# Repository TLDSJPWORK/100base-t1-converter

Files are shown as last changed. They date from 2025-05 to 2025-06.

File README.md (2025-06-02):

# 100base-t1-converter for Education
学習用 100Base-T1 MediaConnverter

### 特徴
- NXP社のTJA1101とCoreChips社のSR8201F（Realtek社 RTL8201F互換）を使用した 100Base-T1 <-> 100Base-TX のMediaConverterです。
- STM32F103C8T6を搭載したBlue Pill[参考URL](https://en.wikipedia.org/wiki/STM32)を使うことでPHYの設定をMDIOを用いて確認／実施することができ、PHY層の動きを学習することができます。
- オリジナルは Creative Commons Attribution-ShareAlike 4.0 International ライセンスで公開されている[100base-t1-converter](https://github.com/ehntoo/100base-t1-converter)です。作者はehntoo様です。
- 本プロダクトはベースプロダクトから、MDIOでPHYの設定を読み書きするプログラムを追加し、また、[LCSC](https://www.lcsc.com/)で部品を注文するための具体的な部品番号の追加および部品配置の変更と、基板を[JLCPCB](https://jlcpcb.com/)でより安く注文できるように最小ドリル径を変更したものとなります。
- 本プロダクトのライセンスは Creative Commons Attribution-ShareAlike 4.0 International を継承します。

### 基板
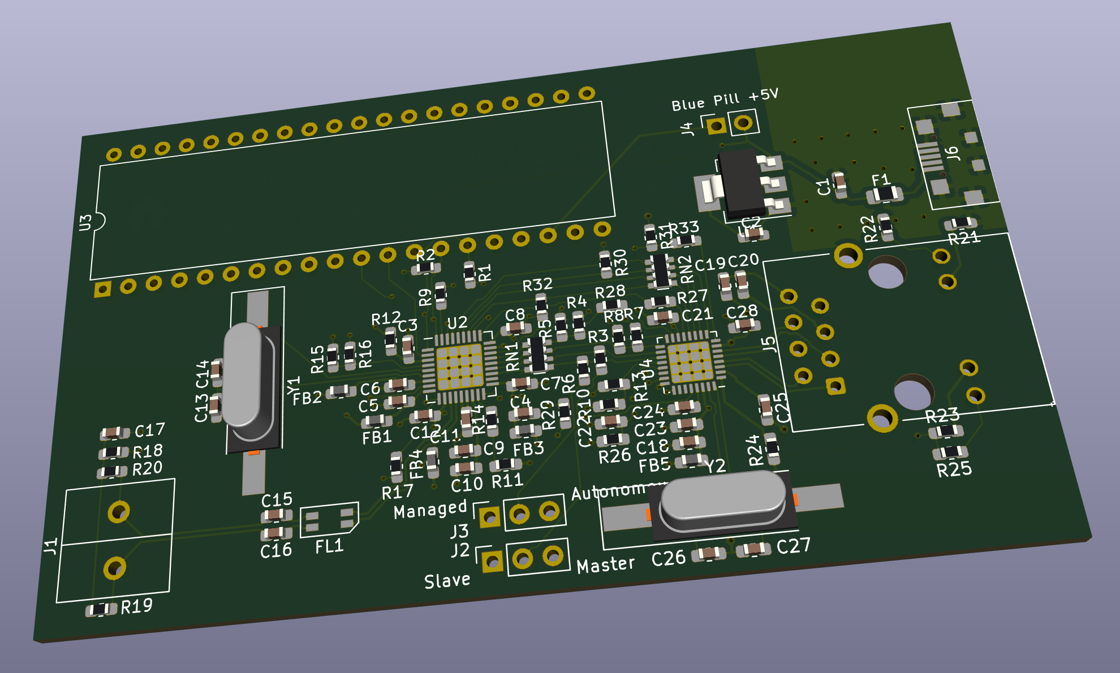
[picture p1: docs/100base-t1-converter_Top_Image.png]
TopImage

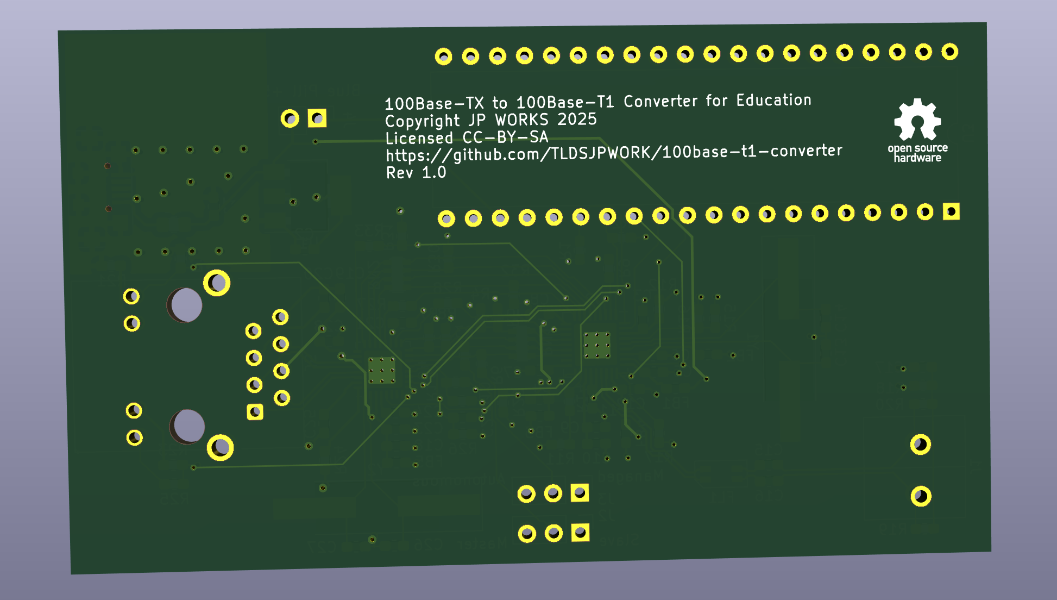
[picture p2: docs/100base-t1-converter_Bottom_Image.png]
BottomImage

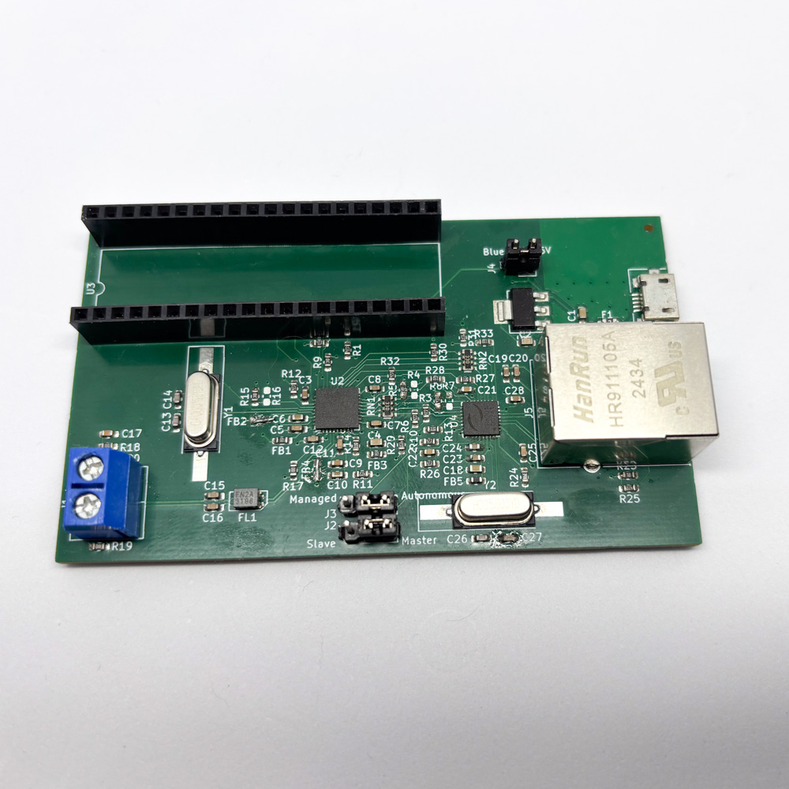
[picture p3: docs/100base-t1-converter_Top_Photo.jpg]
TopPhoto

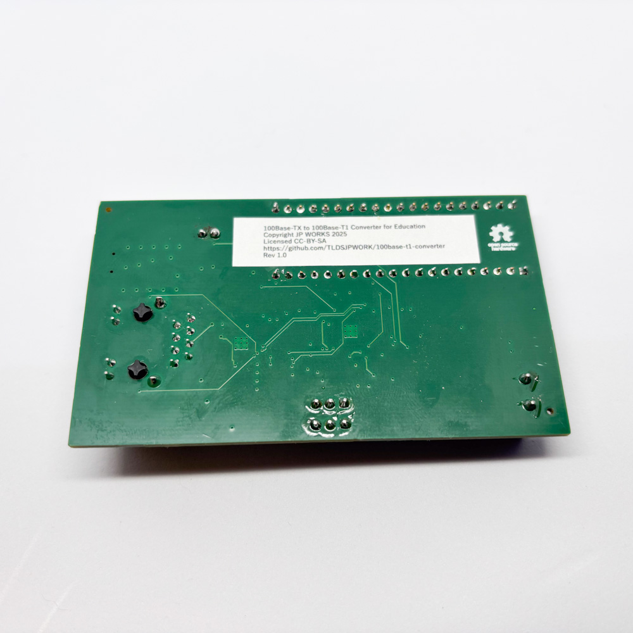
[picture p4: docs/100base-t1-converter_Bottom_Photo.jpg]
BottomPhoto

（※基盤イメージ／写真は参考であり、改良のため変更することがあります）

### 基板の設定
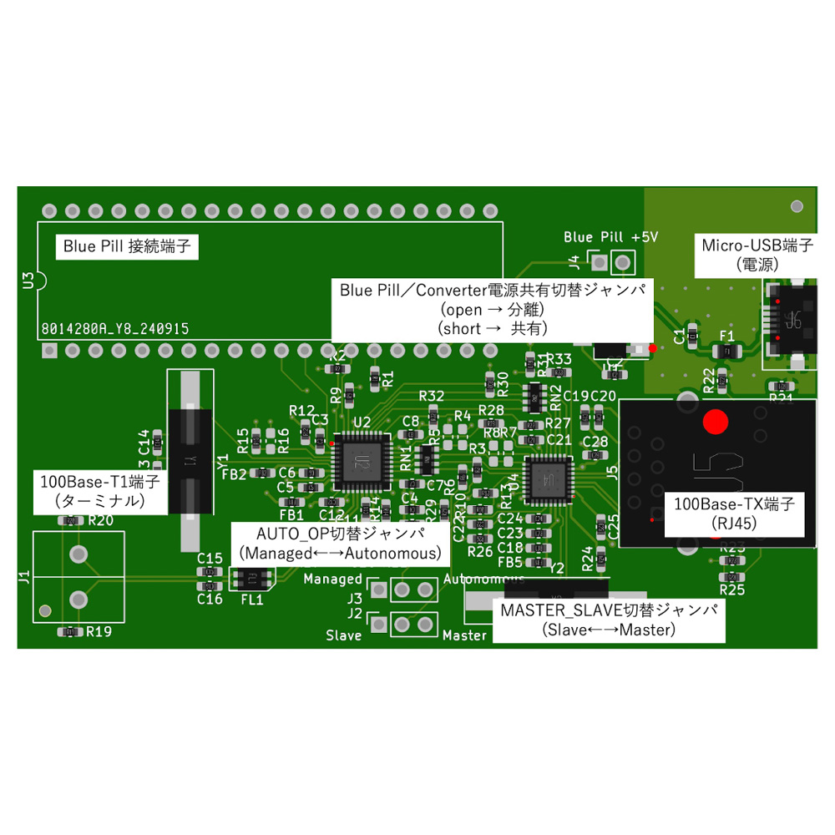
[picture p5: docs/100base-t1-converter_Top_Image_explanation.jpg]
TopImageExplanation


### 使用例
- メディアコンバータとして利用するだけならば、下記ジャンパの設定で、Blue Pillとそれに書き込むソフトウェアの対応は不要です。

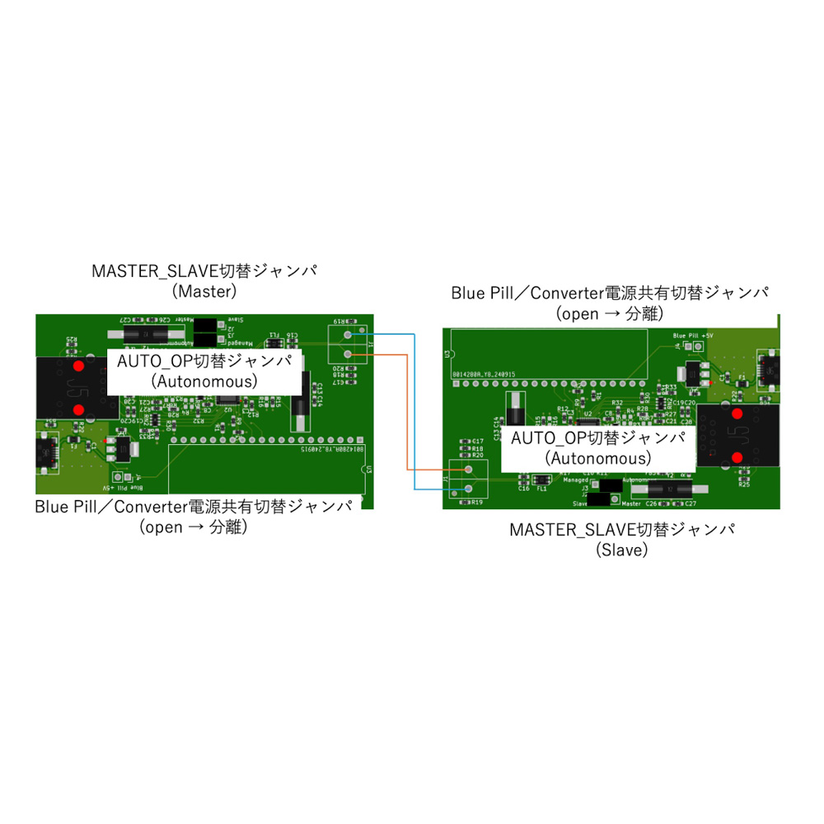
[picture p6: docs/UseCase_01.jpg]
UseCase_01


- Blue Pillにソフトウェアを書き込むことで、MDIOを通してPYHチップの動作確認、変更が可能です。

[レジスター読み書きソフト](/software/phyRegRead/)

- Blue PillをArduinoとして利用し、上記ソフトを書き込むことで、レジスターの読み書きができます。

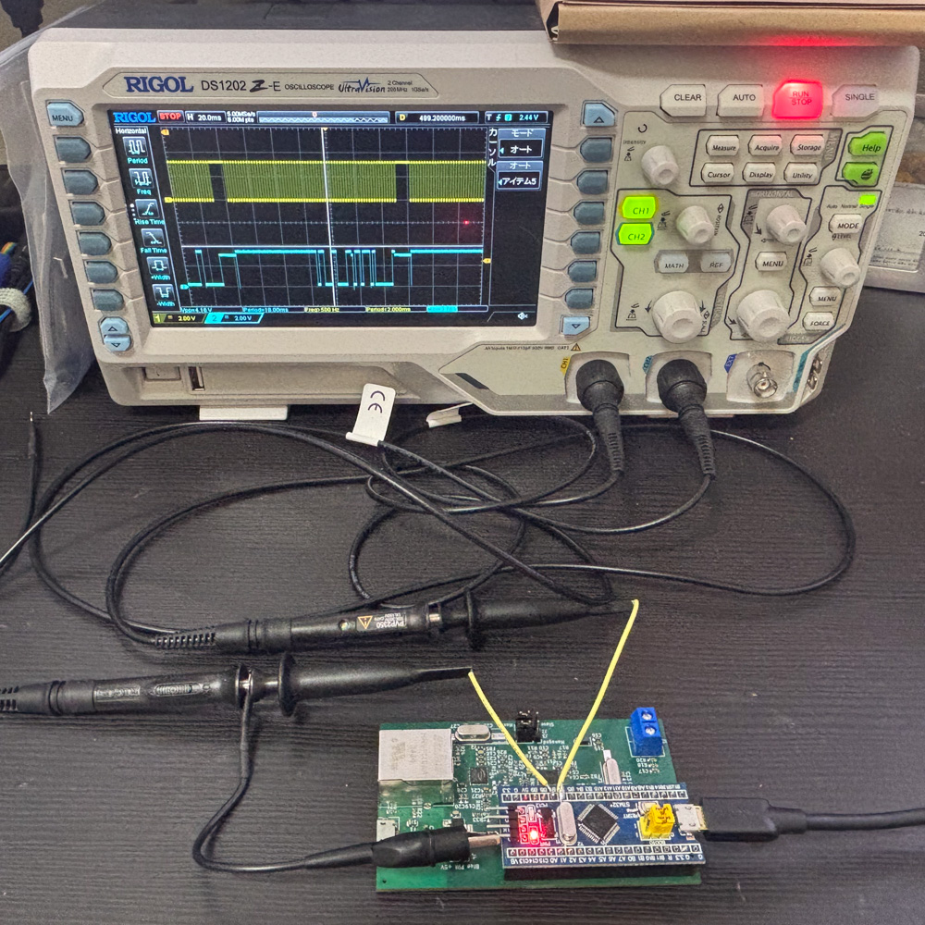
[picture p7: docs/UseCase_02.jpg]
UseCase_03

（ch1がPB7のMDC(Clock)、ch2がPB6のMDIO(Data)です）

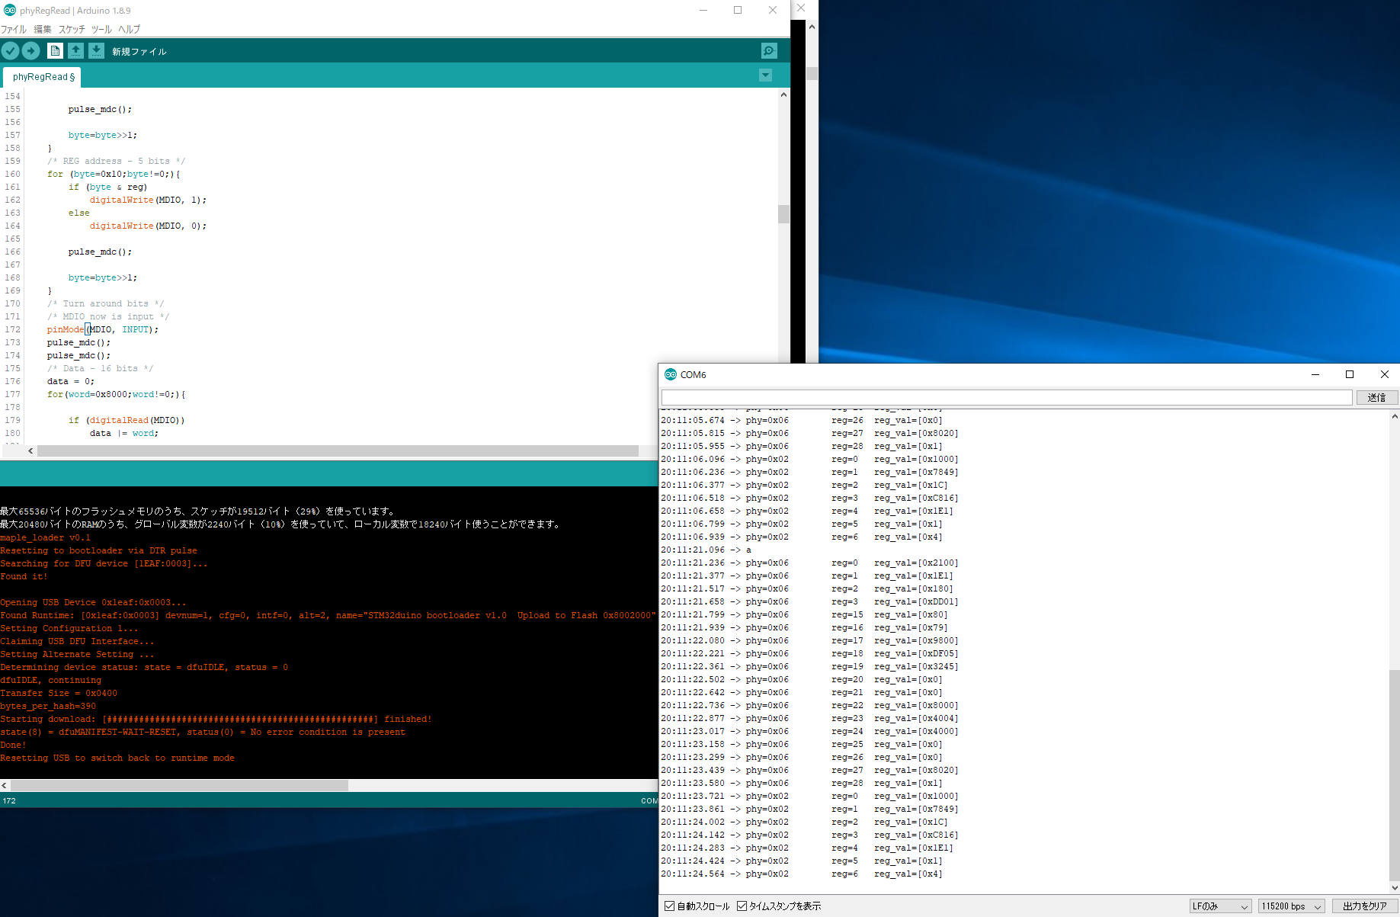
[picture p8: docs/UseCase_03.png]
UseCase_04


- PHYADDR：TJA1101=0x06, SR8201F=0x02
- シリアルコマンド：a 送信=全レジスタ読み出し, r (phyaddr) (register number) 送信=指定レジスタ読出, w (phyaddr) (register number) (レジスタ値) 送信=指定レジスタ書込

### 販売ページ

- スイッチサイエンス様

### 資料

- [サポートページ](https://github.com/TLDSJPWORK/100base-t1-converter)
- [回路図](docs/100base-t1-converter.pdf)
- [TJA1101データシート](https://www.nxp.com/docs/en/data-sheet/TJA1101B.pdf)
- [SR8201Fデータシート](https://www.lcsc.com/datasheet/lcsc_datasheet_2409272302_CoreChips-SR8201F_C378491.pdf) 
- [Blue Pill](https://en.wikipedia.org/wiki/STM32)
- [STM32F103 ボードを Arduino ライクに使う](https://ht-deko.com/arduino/stm32f103c8t6.html)
- [MDIOとは | Ethernet(イーサネット)技術コラム](https://www.e-nexty.com/static/articles/column_ethernet_mdio)

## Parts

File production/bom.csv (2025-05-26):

Designator | Footprint | Quantity | Value | LCSC Part #
C1, C18, C2, C4 | 603 | 4 | 10uF | C96446
C10, C6, C9 | 603 | 3 | 0.47uF | C1623
C11, C12, C15, C16, C19, C20, C21, C22, C23, C24, C25, C28, C3, C5, C7, C8 | 603 | 16 | 0.1uF | C14663
C13, C14, C26, C27 | 603 | 4 | 27pF | C1647
C17 | 603 | 1 | 4700pF | C53987
F1 | 805 | 1 | 500mA | C516070
FB1, FB3 | 603 | 2 | 120R | C22787
FB2, FB4 | 603 | 2 | 0
FB5 | 603 | 1 | BLM18PG181SN1D | C82850
FL1 | SOIC-4 | 1 | ACT1210L-201-2P-TL00 | C131444
J1 | SIP-2 | 1 | Conn_01x02
J2, J3 | PinSocket_1x03_P2.54mm_Vertical | 2 | Conn_01x03
J4 | PinSocket_1x02_P2.54mm_Vertical | 1 | Conn_01x02
J5 | RJ45_Hanrun_HR911105A | 1 | 8P8C_LED_Shielded | C12074
J6 | LCSC_C77238 | 1 | USB_B_Micro | C77238
R1, R10, R11, R12, R2, R22, R25, R26, R29, R3, R30, R31, R32, R6 | 603 | 14 | 4.7k | C23162
R13, R14, R27, R28, R33 | 603 | 5 | 33 | C23140
R15, R9 | 603 | 2 | 10k | C25804
R16, R4, R5, R7, R8 | 603 | 5 | DNP
R17, R18 | 603 | 2 | 100k | C25803
R19, R20 | 603 | 2 | 1.0k | C21190
R21, R23 | 603 | 2 | 510 | C23193
R24 | 603 | 1 | 2.49k 1% | C108190
RN1 | R_Array_Convex_Reversed_4x0603 | 1 | 33 | C25508
RN2 | R_Array_Convex_Reversed_4x0603 | 1 | 33R | C25508
U1 | SOT-223-3_TabPin2 | 1 | AP1117-33 | C115288
U2 | QFN-36-1EP_6x6mm_P0.5mm_EP4.1x4.1mm_ThermalVias | 1 | TJA1101 | C2671511
U3 | DIP-40_W15.24mm | 1 | blue_pill
U4 | QFN-32-1EP_5x5mm_P0.5mm_EP3.6x3.6mm_ThermalVias | 1 | SR8201F | C378491
Y1, Y2 | Crystal_SMD_HC49-SD_HandSoldering | 2 | TXC 9C25000026 | C2890202

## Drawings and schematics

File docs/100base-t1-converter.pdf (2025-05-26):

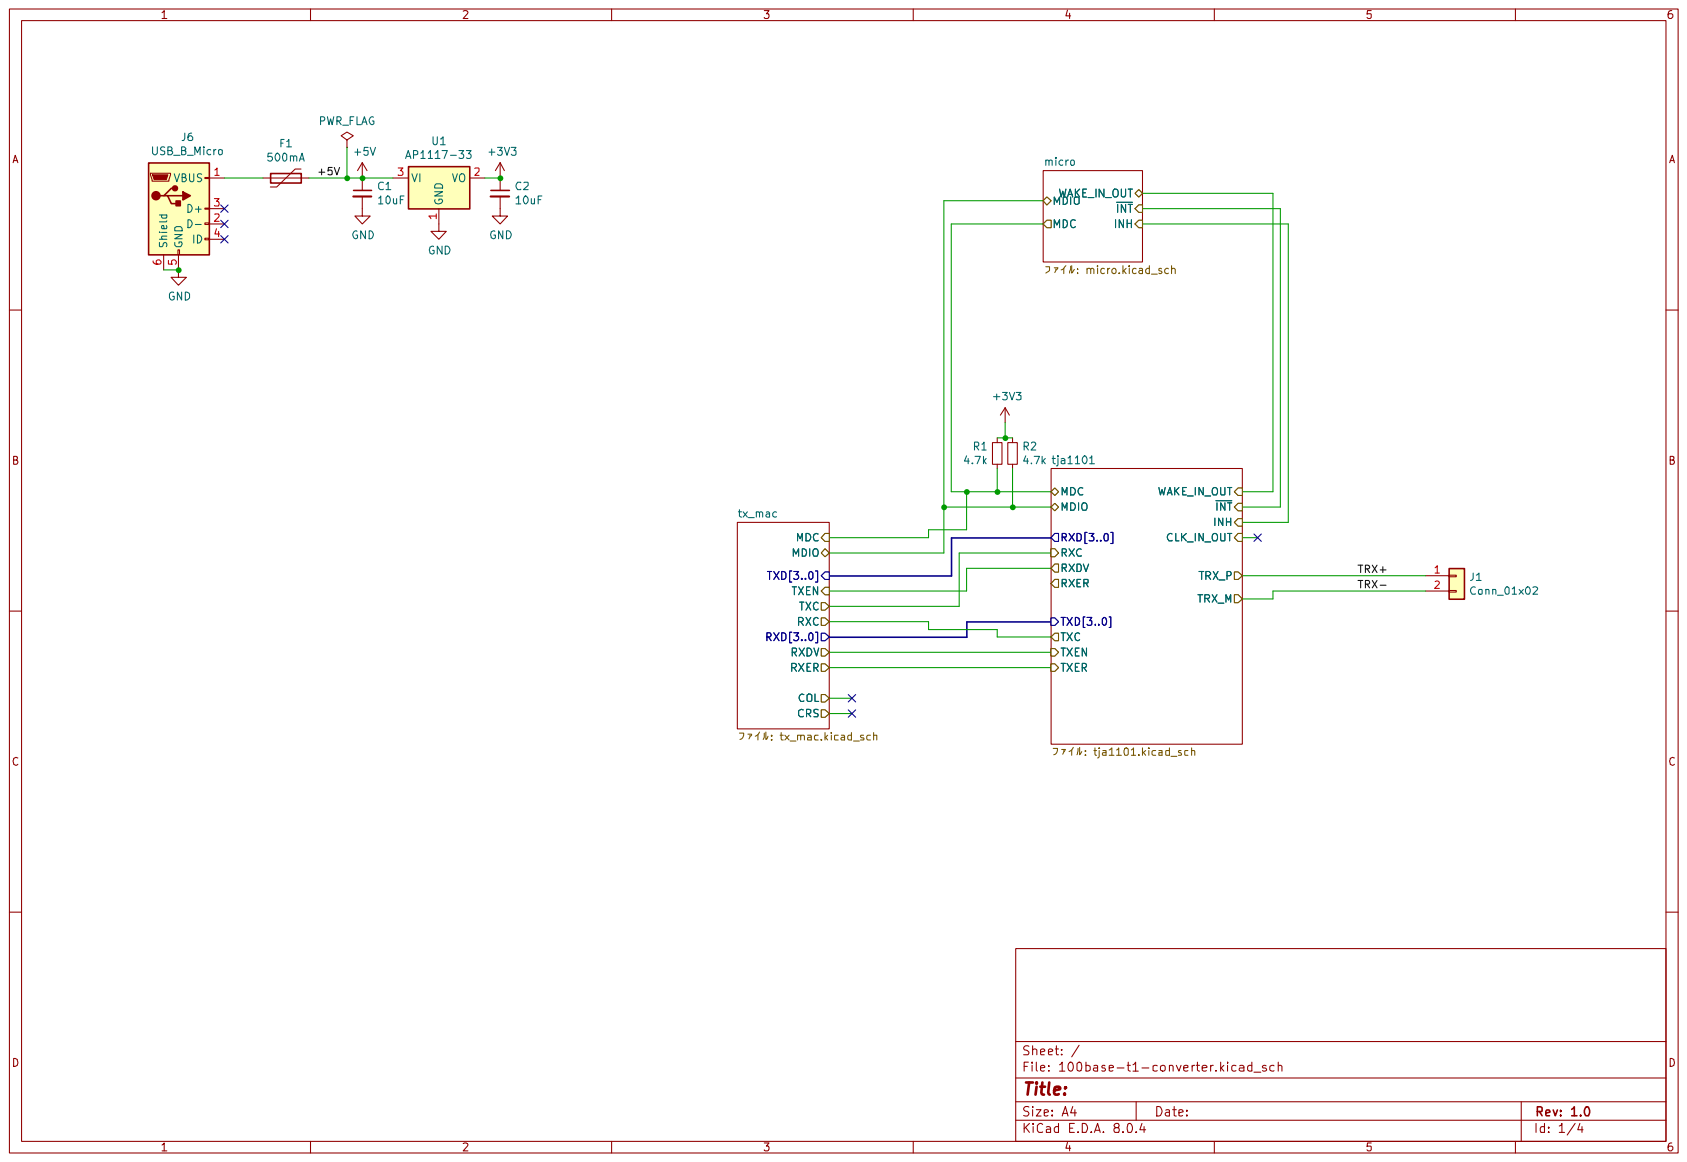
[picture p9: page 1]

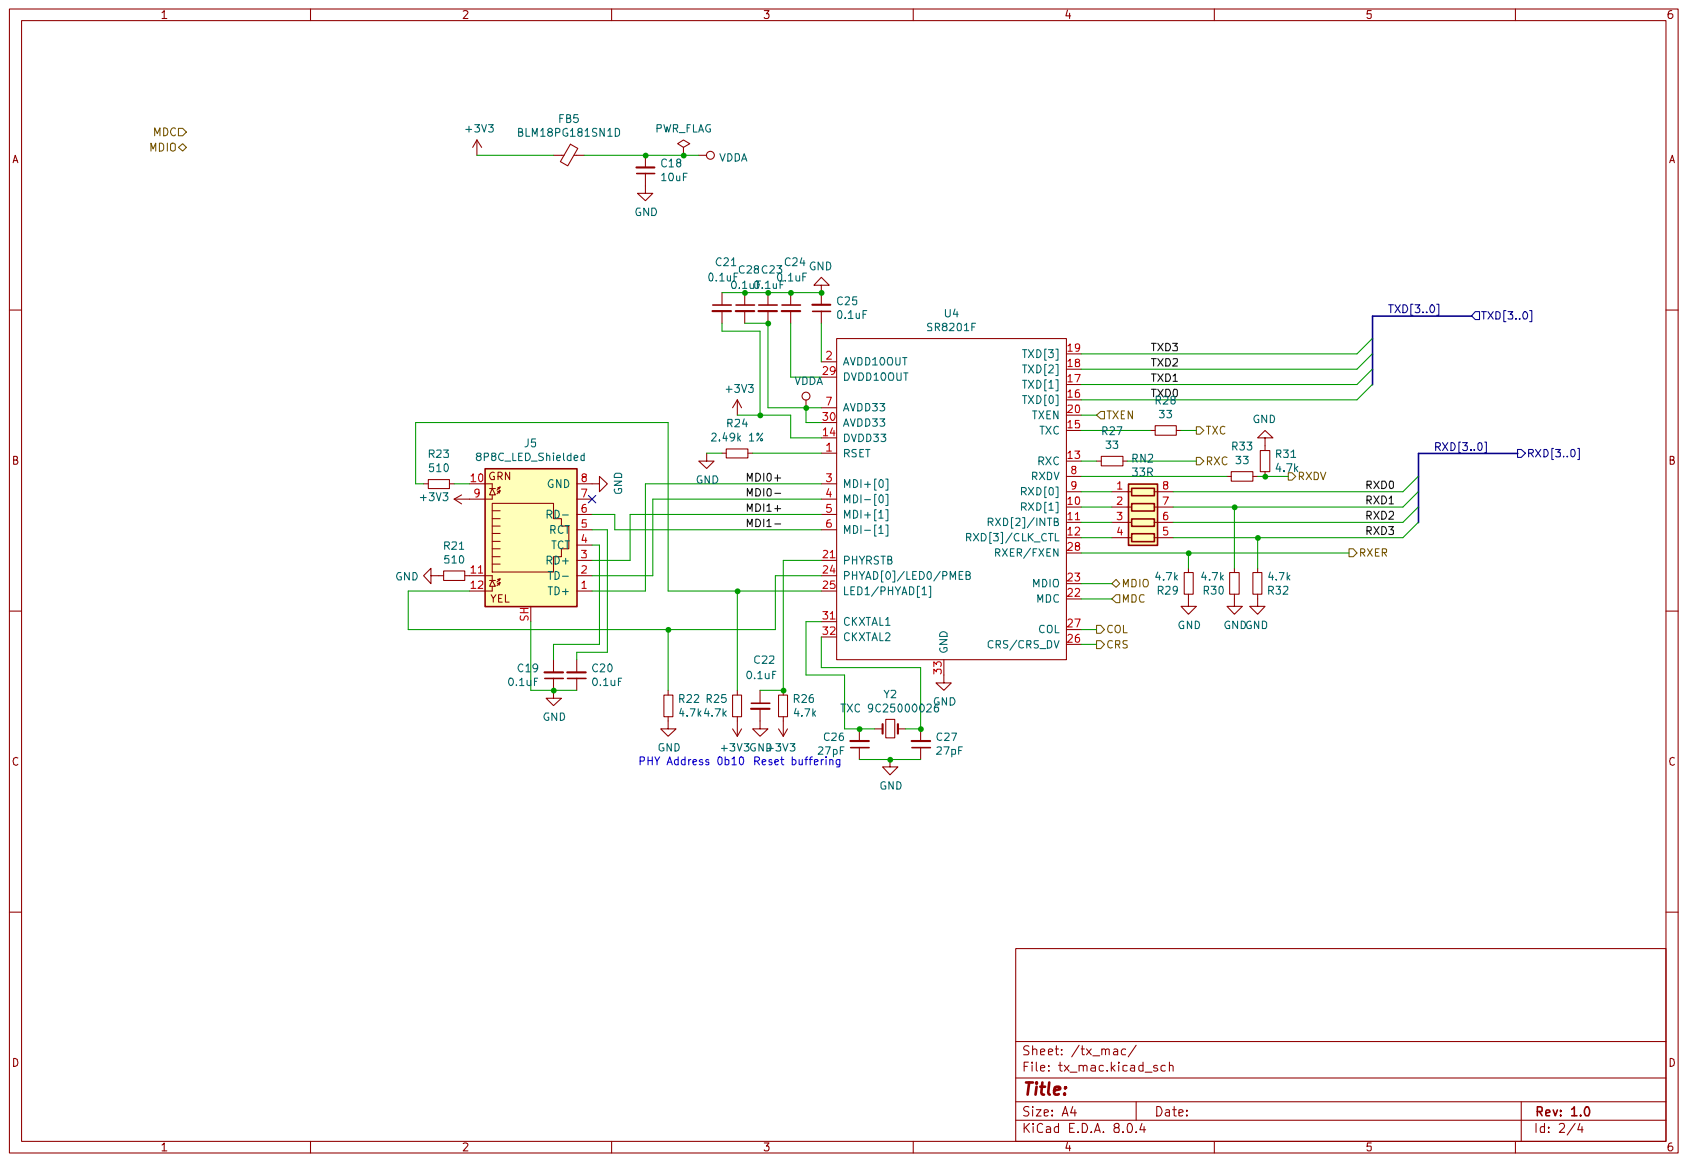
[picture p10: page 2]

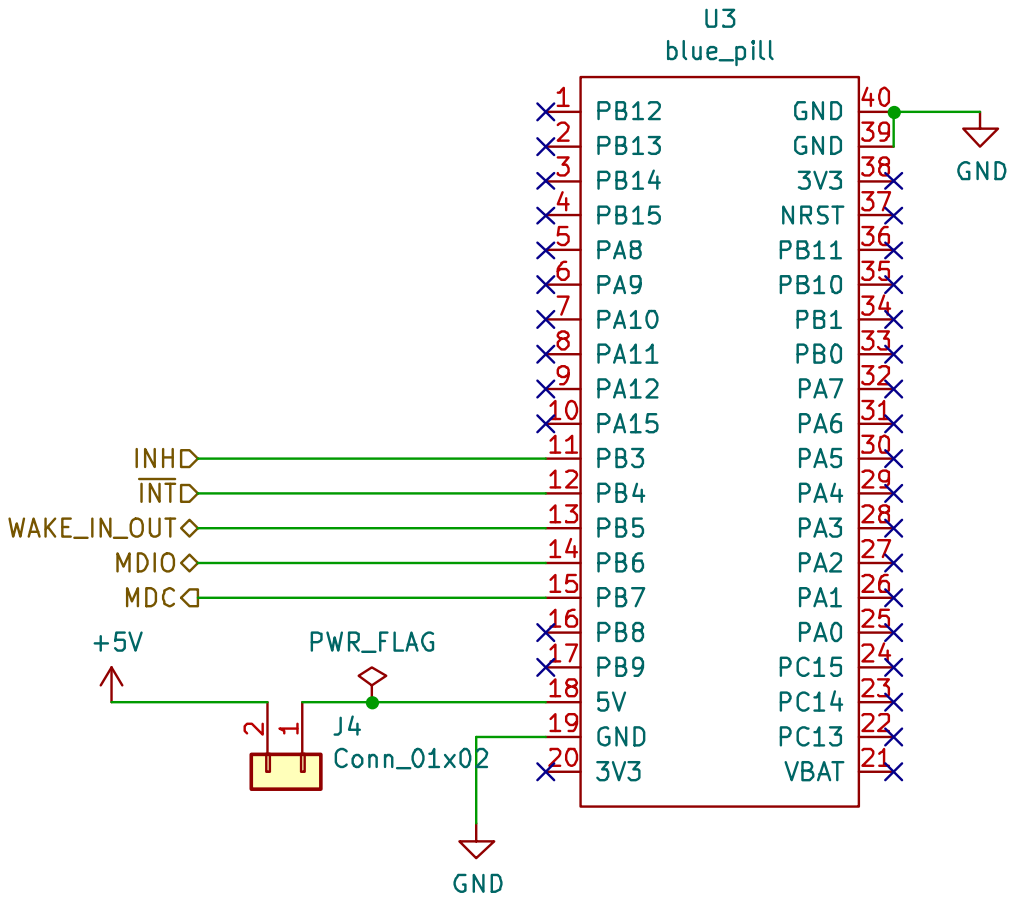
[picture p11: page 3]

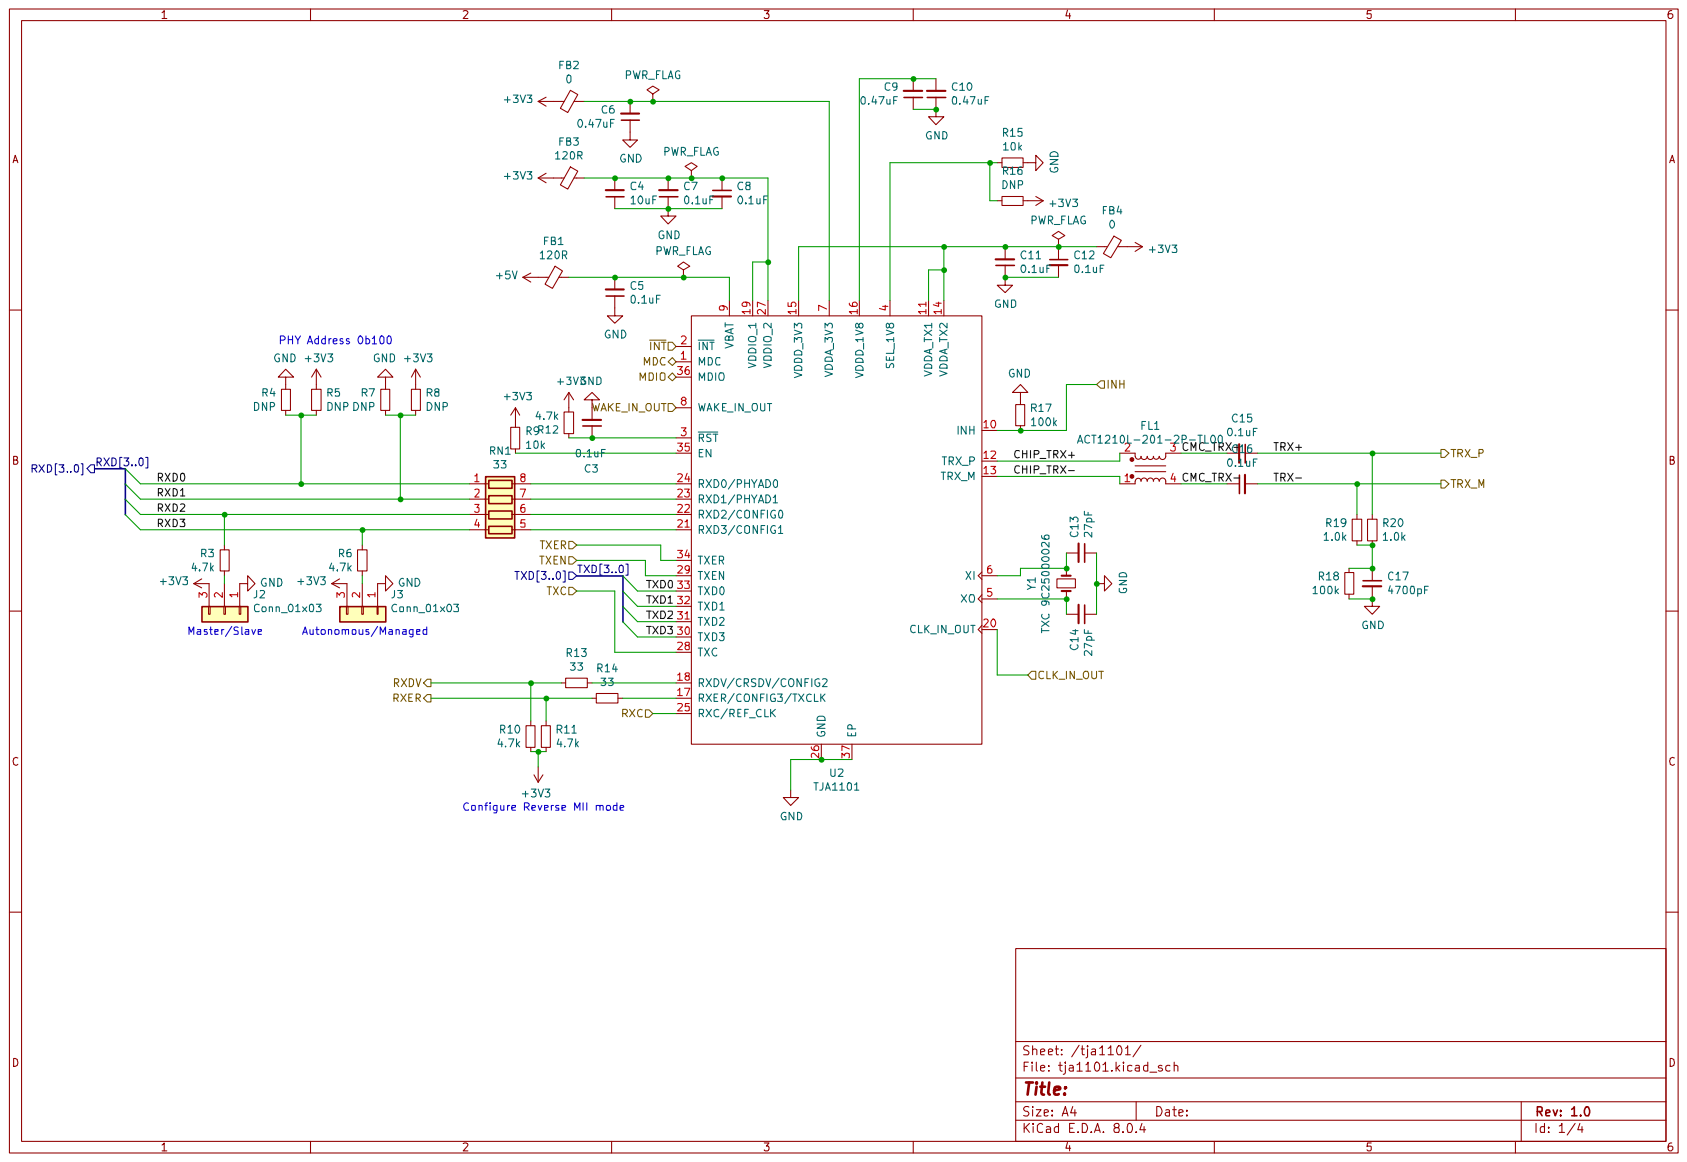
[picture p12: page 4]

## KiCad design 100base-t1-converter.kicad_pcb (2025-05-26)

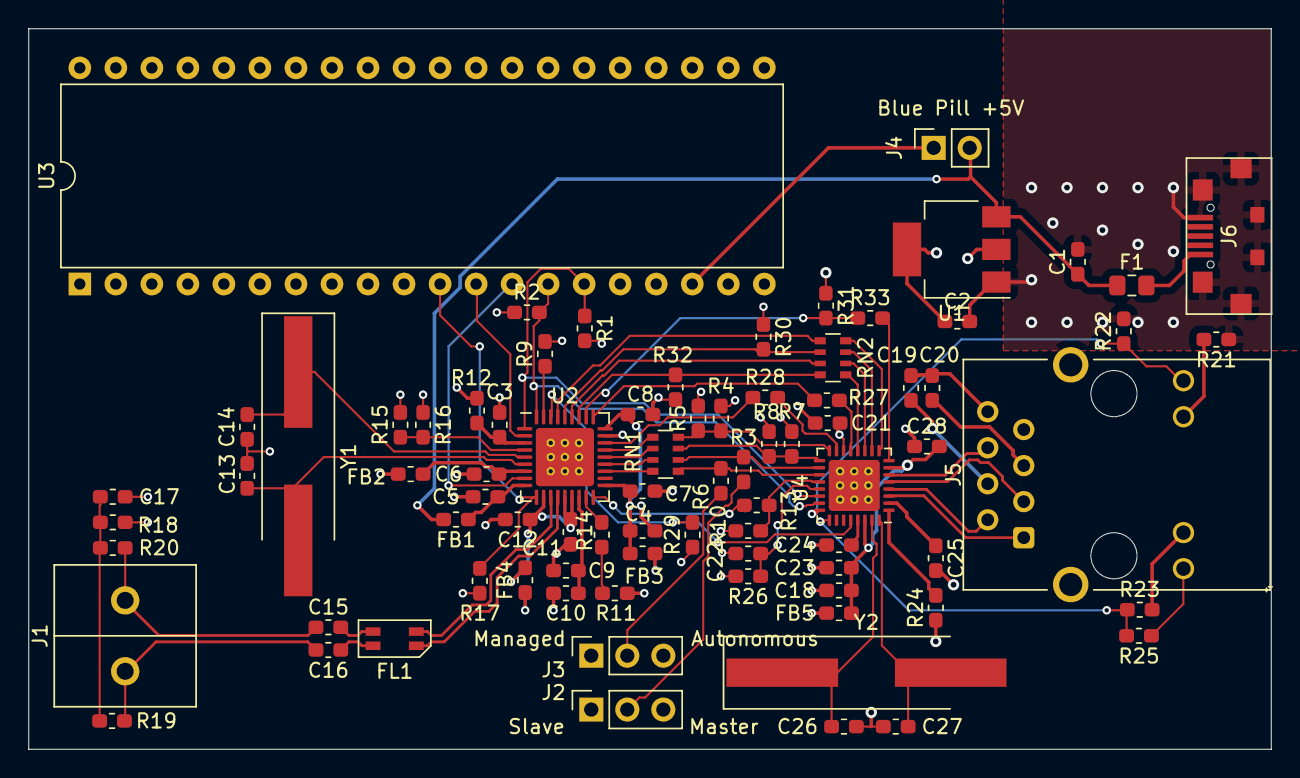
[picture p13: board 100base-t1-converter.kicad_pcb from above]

Board: 4 copper layers, 87.6 x 50.8 mm, 82 parts (0 on the bottom side), 50 nets.

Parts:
C1, C2, C4, C18: 10uF; C_0603_1608Metric_Pad1.05x0.95mm_HandSolder
C3, C5, C7, C8, C11, C12, C15, C16, C19, C20, C21, C22, C23, C24, C25, C28: 0.1uF; C_0603_1608Metric_Pad1.05x0.95mm_HandSolder
C6, C9, C10: 0.47uF; C_0603_1608Metric_Pad1.05x0.95mm_HandSolder
C13, C14, C26, C27: 27pF; C_0603_1608Metric_Pad1.05x0.95mm_HandSolder
C17: 4700pF; C_0603_1608Metric_Pad1.05x0.95mm_HandSolder
F1: 500mA; Fuse_0805_2012Metric_Pad1.15x1.40mm_HandSolder
FB1, FB3: 120R; L_0603_1608Metric_Pad1.05x0.95mm_HandSolder
FB2, FB4: 0; L_0603_1608Metric_Pad1.05x0.95mm_HandSolder
FB5: BLM18PG181SN1D; L_0603_1608Metric_Pad1.05x0.95mm_HandSolder
FL1: ACT1210L-201-2P-TL00; SOIC-4
J1: Conn_01x02; SIP-2
J2, J3: Conn_01x03; PinSocket_1x03_P2.54mm_Vertical
J4: Conn_01x02; PinSocket_1x02_P2.54mm_Vertical
J5: 8P8C_LED_Shielded; RJ45_Hanrun_HR911105A
J6: USB_B_Micro; LCSC_C77238
R1, R2, R3, R6, R10, R11, R12, R22, R25, R26, R29, R30, R31, R32: 4.7k; R_0603_1608Metric_Pad1.05x0.95mm_HandSolder
R4, R5, R7, R8, R16: DNP; R_0603_1608Metric_Pad1.05x0.95mm_HandSolder
R9, R15: 10k; R_0603_1608Metric_Pad1.05x0.95mm_HandSolder
R13, R14, R27, R28, R33: 33; R_0603_1608Metric_Pad1.05x0.95mm_HandSolder
R17, R18: 100k; R_0603_1608Metric_Pad1.05x0.95mm_HandSolder
R19, R20: 1.0k; R_0603_1608Metric_Pad1.05x0.95mm_HandSolder
R21, R23: 510; R_0603_1608Metric_Pad1.05x0.95mm_HandSolder
R24: 2.49k 1%; R_0603_1608Metric_Pad1.05x0.95mm_HandSolder
RN1: 33; R_Array_Convex_Reversed_4x0603
RN2: 33R; R_Array_Convex_Reversed_4x0603
U1: AP1117-33; SOT-223-3_TabPin2
U2: TJA1101; QFN-36-1EP_6x6mm_P0.5mm_EP4.1x4.1mm_ThermalVias
U3: blue_pill; DIP-40_W15.24mm
U4: SR8201F; QFN-32-1EP_5x5mm_P0.5mm_EP3.6x3.6mm_ThermalVias
Y1, Y2: TXC 9C25000026; Crystal_SMD_HC49-SD_HandSoldering

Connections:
+3V3: C2.1, C21.2, FB2.2, FB3.2, FB4.1, FB5.2, J2.3, J3.3, J5.9, R1.2, R2.1, R5.2, R8.2, R9.2, R10.1, R11.1, R12.2, R16.1, R25.1, R26.2, U1.2 (VO), U4.14 (DVDD33)
+5V: C1.1, F1.1, FB1.2, J4.2, U1.3 (VI)
/TRX+: C15.1, J1.1, R20.2
/TRX-: C16.2, J1.2, R19.2
/micro/INH: R17.1, U2.10 (INH), U3.11 (PB3)
/micro/MDC: R1.1, U2.1 (MDC), U3.15 (PB7), U4.22 (MDC)
/micro/MDIO: R2.2, U2.36 (MDIO), U3.14 (PB6), U4.23 (MDIO)
/micro/WAKE_IN_OUT: U2.8 (WAKE_IN_OUT), U3.13 (PB5)
/micro/~INT: U2.2 (~INT), U3.12 (PB4)
/tja1101/CHIP_TRX+: FL1.2, U2.12 (TRX_P)
/tja1101/CHIP_TRX-: FL1.1, U2.13 (TRX_M)
/tja1101/CMC_TRX+: C15.2, FL1.3
/tja1101/CMC_TRX-: C16.1, FL1.4
/tja1101/RXC: R28.1, U2.25 (RXC/REF_CLK)
/tja1101/RXD0: R4.1, R5.1, RN1.1 (R1.1), U4.16 (TXD[0])
/tja1101/RXD1: R7.1, R8.1, RN1.2 (R2.1), U4.17 (TXD[1])
/tja1101/RXD2: R3.2, RN1.3 (R3.1), U4.18 (TXD[2])
/tja1101/RXD3: R6.2, RN1.4 (R4.1), U4.19 (TXD[3])
/tja1101/RXDV: R10.2, R13.2, U4.20 (TXEN)
/tja1101/RXER: R11.2, R14.2
/tja1101/TXC: R27.1, U2.28 (TXC)
/tja1101/TXD0: RN2.8 (R1.2), U2.33 (TXD0)
/tja1101/TXD1: R30.2, RN2.7 (R2.2), U2.32 (TXD1)
/tja1101/TXD2: RN2.6 (R3.2), U2.31 (TXD2)
/tja1101/TXD3: R32.2, RN2.5 (R4.2), U2.30 (TXD3)
/tja1101/TXEN: R31.2, R33.1, U2.29 (TXEN)
/tja1101/TXER: R29.2, U2.34 (TXER), U4.28 (RXER/FXEN)
/tx_mac/MDI0+: J5.1 (TD+), U4.3 (MDI+[0])
/tx_mac/MDI0-: J5.2 (TD-), U4.4 (MDI-[0])
/tx_mac/MDI1+: J5.3 (RD+), U4.5 (MDI+[1])
/tx_mac/MDI1-: J5.6 (RD-), U4.6 (MDI-[1])
GND: C1.2, C2.2, C3.2, C4.1, C5.1, C6.1, C7.1, C8.2, C9.1, C10.1, C11.1, C12.2, C13.1, C14.1, C17.2, C18.1, C19.1, C20.1, C21.1, C22.2, C23.1, C24.1, C25.2, C26.1, C27.1, C28.1, J2.1, J3.1, J5.8 (GND), J5.SH, J6.5 (GND), J6.6 (Shield), R4.2, R7.2, R15.2, R17.2, R18.1, R21.1, R22.2, R24.1, R29.1, R30.1, R31.1, R32.1, U1.1 (GND), U2.26 (GND), U2.37 (EP), U3.19 (GND), U3.39 (GND), U3.40 (GND), U4.33 (GND)
unnamed: C3.1, R12.1, U2.3 (~RST)
unnamed: C13.2, U2.6 (XI), Y1.2
unnamed: C14.2, U2.5 (XO), Y1.1
unnamed: C6.2, FB2.1, U2.7 (VDDA_3V3)
unnamed: C11.2, C12.1, FB4.2, U2.11 (VDDA_TX1), U2.14 (VDDA_TX2), U2.15 (VDDD_3V3)
unnamed: F1.2, J6.1 (VBUS)
unnamed: C25.1, U4.2 (AVDD10OUT)
unnamed: C26.2, U4.31 (CKXTAL1), Y2.1
unnamed: C27.2, U4.32 (CKXTAL2), Y2.2
unnamed: C24.2, U4.29 (DVDD10OUT)
unnamed: R23.1, R25.2, U4.25 (LED1/PHYAD[1])
unnamed: J5.12, R22.1, U4.24 (PHYAD[0]/LED0/PMEB)
unnamed: C22.1, R26.1, U4.21 (PHYRSTB)
unnamed: R24.2, U4.1 (RSET)
unnamed: R27.2, U4.13 (RXC)
unnamed: R33.2, U4.8 (RXDV)
unnamed: R28.2, U4.15 (TXC)
VDDA: C18.2, C23.2, C28.2, FB5.1, U4.7 (AVDD33), U4.30 (AVDD33)

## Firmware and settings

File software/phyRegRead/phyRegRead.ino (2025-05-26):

#include <stdio.h>                                                                   
#include <stdlib.h>                                                                  
#include <stdint.h> 

#define MDCIP PB7 // wiringPi PIN for MDCIP                                            
#define MDIO  PB6 // wiringPi PIN for MDIO      

#define MAXARGS 4

String cmds[MAXARGS] = {"\0"}; // 分割された文字列を格納する配列 

int split(String data, char delimiter, String *dst){
    int index = 0; 
    int datalength = data.length();

    dst[0] = "";
    for (int i = 0; i < datalength; i++) {
        char tmp = data.charAt(i);
        if ( tmp == delimiter ) {
            index++;
            dst[index] = "";
        }
        else dst[index] += tmp;
    }
    
    return (index + 1);
}

uint16_t reg_val = 0;
uint8_t reg = 0;

int smi_init(void)                                                                
{                                                                                    
    pinMode(MDCIP, OUTPUT);
    pinMode(MDIO, OUTPUT);
    return 0;
}                                                                                    
                                                                                                                                                                          
/*! Generates a rising edge pulse on IP175 MDC */                                    
void pulse_mdcip(void)                                                               
{                                                                                    
    digitalWrite(MDCIP, 0);                                                          
    delay(1);                                                                       
    digitalWrite(MDCIP, 1);                                                          
    delay(1);                                                                       
}                                                                                    

/*! Performs a smi write */                                                          
void write_smi(uint8_t phy, uint8_t reg, uint16_t data)                              
{                                                                                    
    uint8_t byte;                                                                    
    uint16_t word;                                                                   
                                                                                     
    void (*pulse_mdc)(void);                                                         
    pulse_mdc = pulse_mdcip;                                                         
                                                                                     
    /* MDIO pin is output */                                                         
    pinMode(MDIO, OUTPUT);                                                           
                                                                                     
    digitalWrite(MDIO, 1);                                                           
    for (byte = 0;byte < 32; byte++)                                                 
        pulse_mdc();                                                                 
                                                                                     
    /* Stat code */                                                                  
    digitalWrite(MDIO, 0);                                                           
    pulse_mdc();                                                                     
    digitalWrite(MDIO, 1);                                                           
    pulse_mdc();                                                                     
                                                                                     
    /* Write OP Code */                                                              
    digitalWrite(MDIO, 0);                                                           
    pulse_mdc();                                                                     
    digitalWrite(MDIO, 1);                                                           
    pulse_mdc();                                                                     
                                                                                     
    /* PHY address - 5 bits */                                                       
    for (byte=0x10;byte!=0;byte=byte>>1){                                            
        if (byte & phy)                                                              
            digitalWrite(MDIO, 1);                                                   
        else                                                                         
            digitalWrite(MDIO, 0);                                                   
        pulse_mdc();                                                                 
    }                                                                                
    /* REG address - 5 bits */                                                       
    for (byte=0x10;byte!=0;byte=byte>>1){                                            
        if (byte & reg)                                                              
            digitalWrite(MDIO, 1);                                                   
        else                                                                         
            digitalWrite(MDIO, 0);                                                   
                                                                                     
        pulse_mdc();                                                                 
    }                                                                                
    /* Turn around bits */                                                           
    digitalWrite(MDIO, 1);                                                           
    pulse_mdc();                                                                     
    digitalWrite(MDIO, 0);                                                           
    pulse_mdc();                                                                     
                                                                                     
    /* Data - 16 bits */                                                             
    for(word=0x8000;word!=0;word=word>>1){                                           
        if (word & data)                                                             
            digitalWrite(MDIO, 1);                                                   
        else                                                                         
            digitalWrite(MDIO, 0);                                                   
                                                                                     
        pulse_mdc();                                                                 
    }
                                                                                     
    /* This is needed for some reason... */                                          
    pulse_mdc();                                                                     
    /* Stay in 0 state */                                                            
//  MDCIP = 0;                                                                       
}

uint16_t read_smi(uint8_t phy, uint8_t reg)                                          
{                                                                                    
    uint8_t byte;                                                                    
    uint16_t word, data;                                                             
                                                                                     
    void (*pulse_mdc)(void);                                                         
                                                                                     
    pulse_mdc = pulse_mdcip;                                                         
                                                                                     
    /* MDIO pin is output */                                                         
    pinMode(MDIO, OUTPUT);                                                           
                                                                                     
    digitalWrite(MDIO, 1);                                                           
    for (byte = 0;byte < 32; byte++)                                                 
        pulse_mdc();                                                                 
                                                                                     
    /* Stat code */                                                                  
    digitalWrite(MDIO, 0);                                                           
    pulse_mdc();                                                                     
    digitalWrite(MDIO, 1);                                                           
    pulse_mdc();                                                                     
                                                                                     
    /* Read OP Code */                                                               
    digitalWrite(MDIO, 1);                                                           
    pulse_mdc();                                                                     
    digitalWrite(MDIO, 0);                                                           
    pulse_mdc();                                                                     
                                                                                     
    /* PHY address - 5 bits */                                                       
    for (byte=0x10;byte!=0;){                                                        
        if (byte & phy)                                                              
            digitalWrite(MDIO, 1);                                                   
        else                                                                         
            digitalWrite(MDIO, 0);                                                   
                                                                                     
        pulse_mdc();                                                                 
                                                                                     
        byte=byte>>1;                                                                
    }                                                                                
    /* REG address - 5 bits */                                                       
    for (byte=0x10;byte!=0;){                                                        
        if (byte & reg)                                                              
            digitalWrite(MDIO, 1);                                                   
        else                                                                         
            digitalWrite(MDIO, 0);                                                   
                                                                                     
        pulse_mdc();                                                                 
                                                                                     
        byte=byte>>1;                                                                
    }                                                                                
    /* Turn around bits */                                                           
    /* MDIO now is input */                                                          
    pinMode(MDIO, INPUT);                                                            
    pulse_mdc();                                                                     
    pulse_mdc();                                                                     
    /* Data - 16 bits */                                                             
    data = 0;                                                                        
    for(word=0x8000;word!=0;){                                                       
                                                                                     
        if (digitalRead(MDIO))                                                       
            data |= word;                                                            
                                                                                     
        pulse_mdc();
                                                                         
                                                                                     
        word=word>>1;                                                                
    }                                                                                
                                                                                     
    /* This is needed for some reason... */                                          
    pulse_mdc();                                                                     
    /* Stay in 0 state */                                                            
//  MDCIP = 0;                                                                       
                                                                                     
    return data;                                                                     
}

uint16_t print_read_smi(uint8_t phy, uint8_t reg)
{                                                                                    
  reg_val = read_smi(phy, reg);
  Serial.print("phy=");
  Serial.print(phy, HEX);
  Serial.print("\treg=");
  Serial.print(reg, DEC);
  Serial.print("\treg_val=[0x");
  Serial.print(reg_val, HEX);
  Serial.print("]\n"); 
  delay(10);
}

void read_registers() {
  //TJA1011A
  reg = 0;
  reg_val = read_smi(0x06, reg);
  Serial.print("phy=0x06\t");
  Serial.print("reg=");
  Serial.print(reg, DEC);
  Serial.print("\treg_val=[0x");
  Serial.print(reg_val, HEX);
  Serial.print("]\n"); 
  delay(10);
  reg = 1;
  reg_val = read_smi(0x06, reg);
  Serial.print("phy=0x06\t");
  Serial.print("reg=");
  Serial.print(reg, DEC);
  Serial.print("\treg_val=[0x");
  Serial.print(reg_val, HEX);
  Serial.print("]\n"); 
  delay(10);
  reg = 2;
  reg_val = read_smi(0x06, reg);
  Serial.print("phy=0x06\t");
  Serial.print("reg=");
  Serial.print(reg, DEC);
  Serial.print("\treg_val=[0x");
  Serial.print(reg_val, HEX);
  Serial.print("]\n"); 
  delay(10);
  reg = 3;
  reg_val = read_smi(0x06, reg);
  Serial.print("phy=0x06\t");
  Serial.print("reg=");
  Serial.print(reg, DEC);
  Serial.print("\treg_val=[0x");
  Serial.print(reg_val, HEX);
  Serial.print("]\n"); 
  delay(10);
  reg = 15;
  reg_val = read_smi(0x06, reg);
  Serial.print("phy=0x06\t");
  Serial.print("reg=");
  Serial.print(reg, DEC);
  Serial.print("\treg_val=[0x");
  Serial.print(reg_val, HEX);
  Serial.print("]\n"); 
  delay(10);
  reg = 16;
  reg_val = read_smi(0x06, reg);
  Serial.print("phy=0x06\t");
  Serial.print("reg=");
  Serial.print(reg, DEC);
  Serial.print("\treg_val=[0x");
  Serial.print(reg_val, HEX);
  Serial.print("]\n"); 
  delay(10);
  reg = 17;
  reg_val = read_smi(0x06, reg);
  Serial.print("phy=0x06\t");
  Serial.print("reg=");
  Serial.print(reg, DEC);
  Serial.print("\treg_val=[0x");
  Serial.print(reg_val, HEX);
  Serial.print("]\n"); 
  delay(10);
  reg = 18;
  reg_val = read_smi(0x06, reg);
  Serial.print("phy=0x06\t");
  Serial.print("reg=");
  Serial.print(reg, DEC);
  Serial.print("\treg_val=[0x");
  Serial.print(reg_val, HEX);
  Serial.print("]\n"); 
  delay(10);
  reg = 19;
  reg_val = read_smi(0x06, reg);
  Serial.print("phy=0x06\t");
  Serial.print("reg=");
  Serial.print(reg, DEC);
  Serial.print("\treg_val=[0x");
  Serial.print(reg_val, HEX);
  Serial.print("]\n"); 
  delay(10);
  reg = 20;
  reg_val = read_smi(0x06, reg);
  Serial.print("phy=0x06\t");
  Serial.print("reg=");
  Serial.print(reg, DEC);
  Serial.print("\treg_val=[0x");
  Serial.print(reg_val, HEX);
  Serial.print("]\n"); 
  delay(10);
  reg = 21;
  reg_val = read_smi(0x06, reg);
  Serial.print("phy=0x06\t");
  Serial.print("reg=");
  Serial.print(reg, DEC);
  Serial.print("\treg_val=[0x");
  Serial.print(reg_val, HEX);
  Serial.print("]\n"); 
  delay(10);
  reg = 22;
  reg_val = read_smi(0x06, reg);
  Serial.print("phy=0x06\t");
  Serial.print("reg=");
  Serial.print(reg, DEC);
  Serial.print("\treg_val=[0x");
  Serial.print(reg_val, HEX);
  Serial.print("]\n"); 
  delay(10);
  reg = 23;
  reg_val = read_smi(0x06, reg);
  Serial.print("phy=0x06\t");
  Serial.print("reg=");
  Serial.print(reg, DEC);
  Serial.print("\treg_val=[0x");
  Serial.print(reg_val, HEX);
  Serial.print("]\n"); 
  delay(10);
  reg = 24;
  reg_val = read_smi(0x06, reg);
  Serial.print("phy=0x06\t");
  Serial.print("reg=");
  Serial.print(reg, DEC);
  Serial.print("\treg_val=[0x");
  Serial.print(reg_val, HEX);
  Serial.print("]\n"); 
  delay(10);
  reg = 25;
  reg_val = read_smi(0x06, reg);
  Serial.print("phy=0x06\t");
  Serial.print("reg=");
  Serial.print(reg, DEC);
  Serial.print("\treg_val=[0x");
  Serial.print(reg_val, HEX);
  Serial.print("]\n"); 
  delay(10);
  reg = 26;
  reg_val = read_smi(0x06, reg);
  Serial.print("phy=0x06\t");
  Serial.print("reg=");
  Serial.print(reg, DEC);
  Serial.print("\treg_val=[0x");
  Serial.print(reg_val, HEX);
  Serial.print("]\n"); 
  delay(10);
  reg = 27;
  reg_val = read_smi(0x06, reg);
  Serial.print("phy=0x06\t");
  Serial.print("reg=");
  Serial.print(reg, DEC);
  Serial.print("\treg_val=[0x");
  Serial.print(reg_val, HEX);
  Serial.print("]\n"); 
  delay(10);
  reg = 28;
  reg_val = read_smi(0x06, reg);
  Serial.print("phy=0x06\t");
  Serial.print("reg=");
  Serial.print(reg, DEC);
  Serial.print("\treg_val=[0x");
  Serial.print(reg_val, HEX);
  Serial.print("]\n"); 
  delay(10);

  //SR8201F
  reg = 0;
  reg_val = read_smi(0x02, reg);
  Serial.print("phy=0x02\t");
  Serial.print("reg=");
  Serial.print(reg, DEC);
  Serial.print("\treg_val=[0x");
  Serial.print(reg_val, HEX);
  Serial.print("]\n"); 
  delay(10);
  reg = 1;
  reg_val = read_smi(0x02, reg);
  Serial.print("phy=0x02\t");
  Serial.print("reg=");
  Serial.print(reg, DEC);
  Serial.print("\treg_val=[0x");
  Serial.print(reg_val, HEX);
  Serial.print("]\n"); 
  delay(10);
  reg = 2;
  reg_val = read_smi(0x02, reg);
  Serial.print("phy=0x02\t");
  Serial.print("reg=");
  Serial.print(reg, DEC);
  Serial.print("\treg_val=[0x");
  Serial.print(reg_val, HEX);
  Serial.print("]\n"); 
  delay(10);
  reg = 3;
  reg_val = read_smi(0x02, reg);
  Serial.print("phy=0x02\t");
  Serial.print("reg=");
  Serial.print(reg, DEC);
  Serial.print("\treg_val=[0x");
  Serial.print(reg_val, HEX);
  Serial.print("]\n"); 
  delay(10);
  reg = 4;
  reg_val = read_smi(0x02, reg);
  Serial.print("phy=0x02\t");
  Serial.print("reg=");
  Serial.print(reg, DEC);
  Serial.print("\treg_val=[0x");
  Serial.print(reg_val, HEX);
  Serial.print("]\n"); 
  delay(10);
  reg = 5;
  reg_val = read_smi(0x02, reg);
  Serial.print("phy=0x02\t");
  Serial.print("reg=");
  Serial.print(reg, DEC);
  Serial.print("\treg_val=[0x");
  Serial.print(reg_val, HEX);
  Serial.print("]\n"); 
  delay(10);
  reg = 6;
  reg_val = read_smi(0x02, reg);
  Serial.print("phy=0x02\t");
  Serial.print("reg=");
  Serial.print(reg, DEC);
  Serial.print("\treg_val=[0x");
  Serial.print(reg_val, HEX);
  Serial.print("]\n"); 
  delay(10);
}

void setup()
{
  Serial.begin(115200);

  //for STM32
  while(!Serial.isConnected())
    delay(10);
  
  smi_init();
  
  Serial.print("\n");

  Serial.print("Config Start:");
  Serial.print("\n");
}


void loop()
{
  while (Serial.available() == 0) {}   //wait for data available
  String input = Serial.readString();  //read until timeout
  input.trim();
  
  Serial.println(input);
  int index = split(input, ' ', cmds);

  int args[MAXARGS];
  /*for(int i = 0; i < index; i++){
    Serial.println(cmds[i]);
  }*/
  if (!cmds[0].compareTo("a")) {
    read_registers();
  }
  if (!cmds[0].compareTo("r")) {
    args[1] = cmds[1].toInt();
    args[2] = cmds[2].toInt();
    print_read_smi(args[1], args[2]);
  }
  if (!cmds[0].compareTo("w")) {
    args[1] = cmds[1].toInt();
    args[2] = cmds[2].toInt();
    args[3] = cmds[3].toInt();
    write_smi(args[1], args[2], args[3]);
  }
  
}

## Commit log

2025-05-26 JPWORK modify commit
    [100base-t1-converter-B_Courtyard.gbr, 100base-t1-converter-B_Cu.gbl, 100base-t1-converter-B_Fab.gbr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]
2025-05-27 スペル誤りの修正
2025-06-02 誤字修正

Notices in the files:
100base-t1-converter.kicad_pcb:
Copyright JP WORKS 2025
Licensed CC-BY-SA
